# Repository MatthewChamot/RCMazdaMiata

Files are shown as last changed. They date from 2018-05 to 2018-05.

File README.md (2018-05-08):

# RCMazdaMiata
Project by Matthew Chamot

Arduino code and CAD for a remote-controlled scale model of a Mazda Miata.

After building a few plastic model cars, I wished they could actually move and I could race them around like an RC car.  This project does exactly that.  A 1:24 scale model of a Mazda Miata had its plastic engine swapped with an electric motor and it was off to the races.

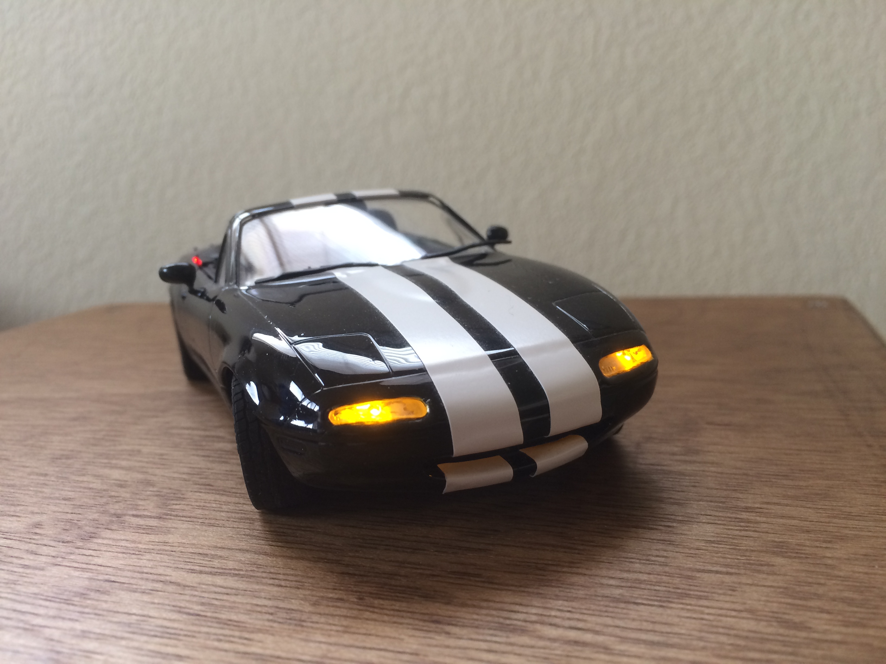
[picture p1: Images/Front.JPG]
miata image


#### Description
The RC Mazda Miata utilizes a small DC gearmotor for driving, sub-mirco servo for steering, and a Bluetooth module for communication.  The processing power comes from a Teensy LC which handles the signals from the controller. The controller in this case was a simple android phone that sends the commands via Bluetooth. The car also incorporates working headlights and taillights, an embedded charging circuit beneath the license plate, and everything still fits under the body of the original model. 

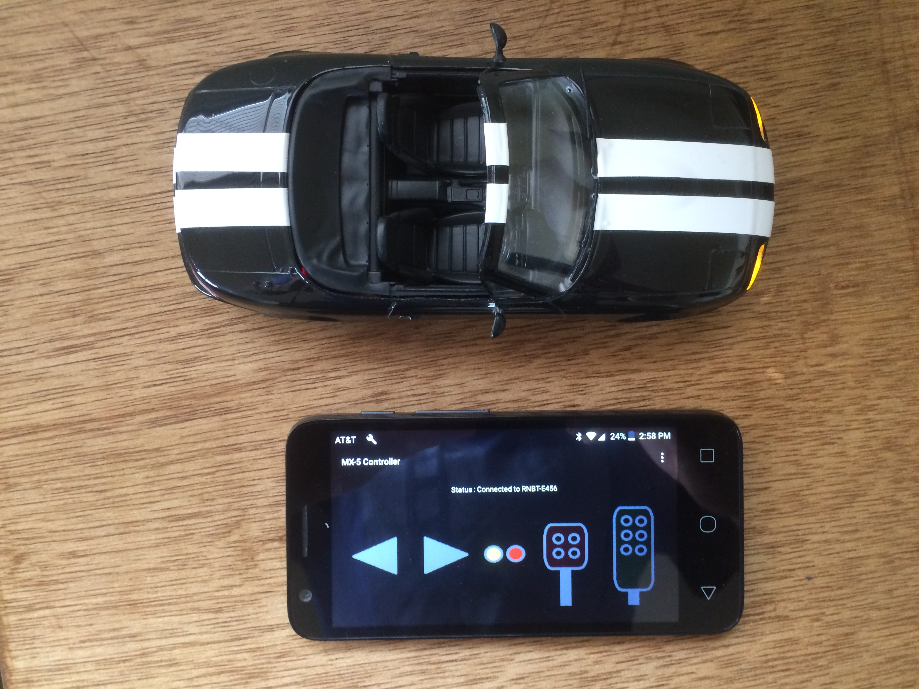
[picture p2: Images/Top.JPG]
miata image

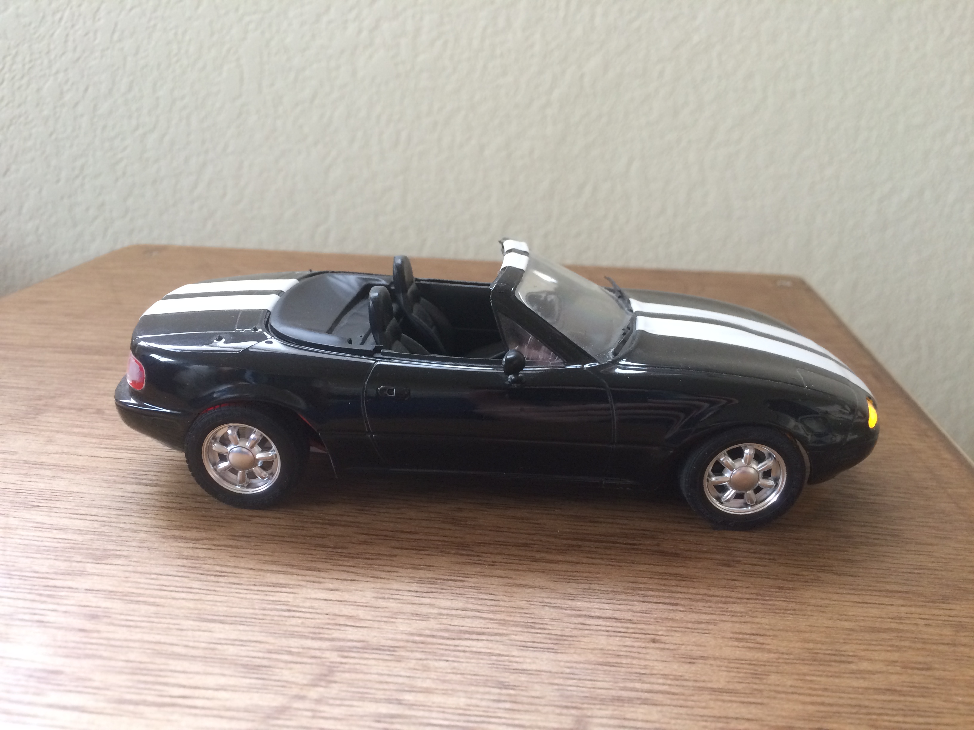
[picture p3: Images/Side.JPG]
miata image

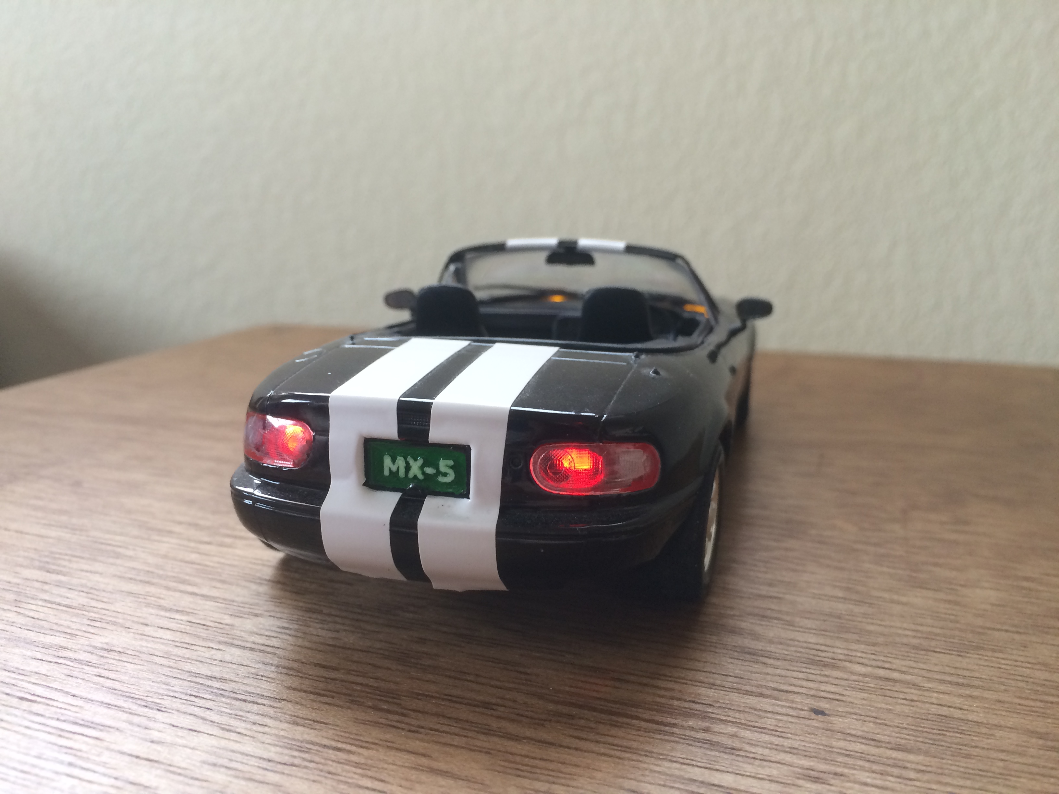
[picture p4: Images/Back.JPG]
miata image


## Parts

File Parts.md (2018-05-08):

## Parts Used

| Part | Quantity | Source |
| --- | :---: | --- |
| Tamiya Mazda Eunos Roadster	 | 1 | eBay				 |
| Micro Gearmotor  		 | 1 | https://www.sparkfun.com/products/12316  |
| Sub-Micro Servo | 1 | https://www.sparkfun.com/products/9065 |
| Teensy LC 		 | 1 | https://www.sparkfun.com/products/13305  |
| SparkFun Bluetooth Modem | 1 | https://www.sparkfun.com/products/12577  |
| SparkFun LiPo Charger Basic | 1 | https://www.sparkfun.com/products/10217  |
| Lithium Ion Battery 		 | 1 | https://www.sparkfun.com/products/13851  |
| Sparkfun Motor Driver 	 | 1 | https://www.sparkfun.com/products/9457 |
| LED - Basic Yellow 3mm  	 | 2 | https://www.sparkfun.com/products/532 |
| LED - Basic Red 3mm 	 | 2 | https://www.sparkfun.com/products/533 |
| SPDT Mini Power Switch 	 | 1  	 | https://www.sparkfun.com/products/102 |

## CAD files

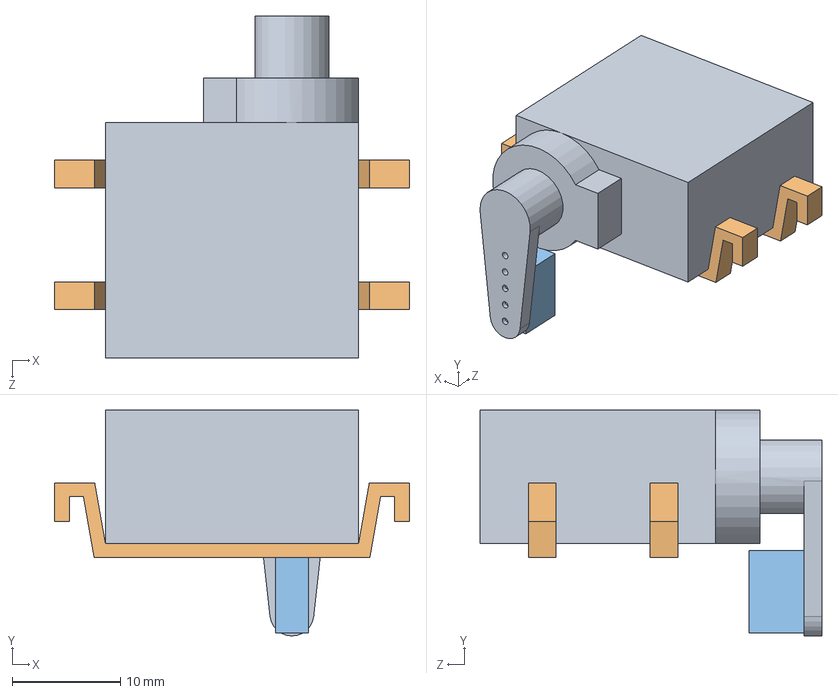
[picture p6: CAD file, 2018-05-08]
Miata_Parts/Servo Assembly.SLDASM
32.8 x 20.9 x 31.5 mm
Servo
Servo Strap x 2
Servo Block

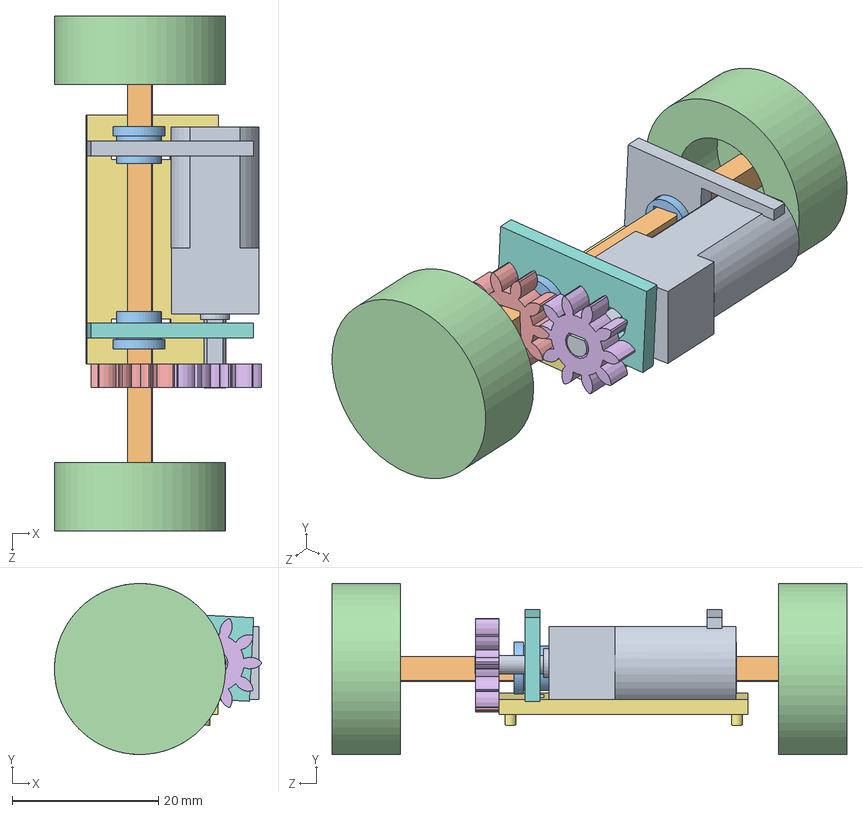
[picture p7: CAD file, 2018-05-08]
Miata_Parts/Motor Assembly.SLDASM
28.3 x 23.4 x 70.3 mm
Motor
Axle
Bushing x 2
Tire x 2
Gear2A
Gear2M
Motor Base
Motor Left
Motor Right

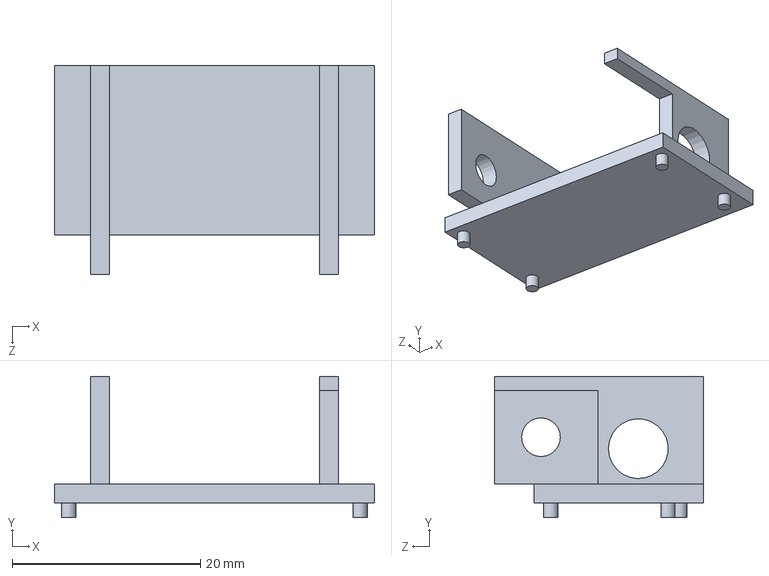
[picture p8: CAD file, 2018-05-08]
Miata_Parts/Motor Mount.SLDPRT
34.0 x 15.0 x 22.2 mm

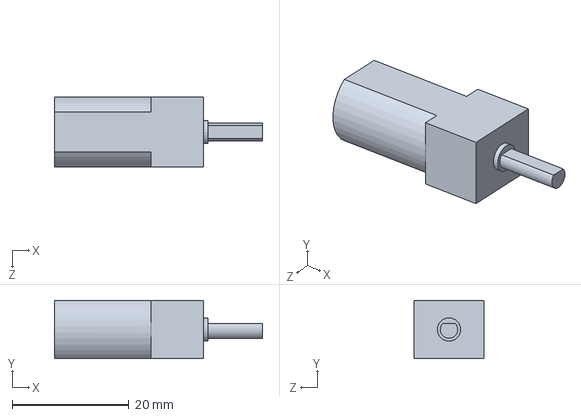
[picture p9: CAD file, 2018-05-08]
Miata_Parts/Motor.SLDPRT
35.6 x 9.96 x 12.0 mm

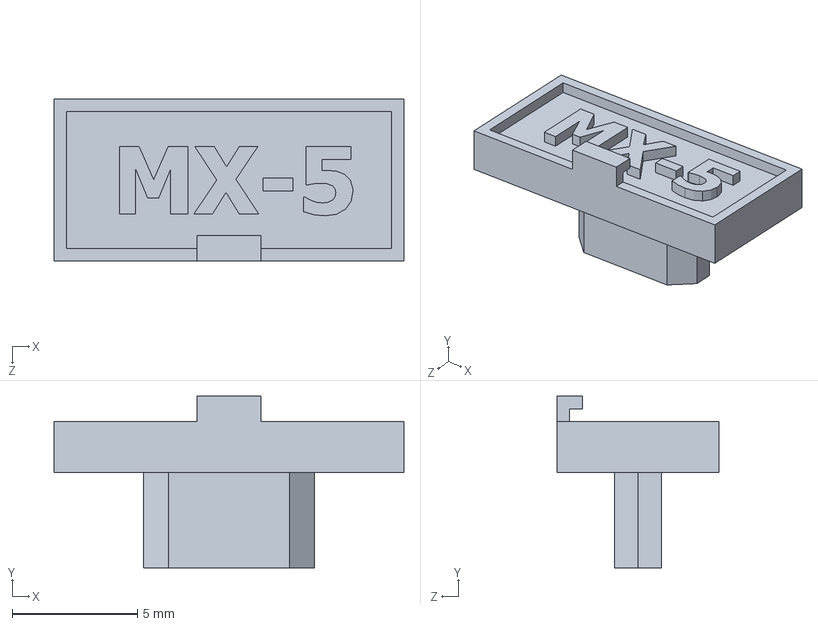
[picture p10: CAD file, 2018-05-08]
Miata_Parts/Plate.SLDPRT
14.0 x 6.86 x 6.48 mm

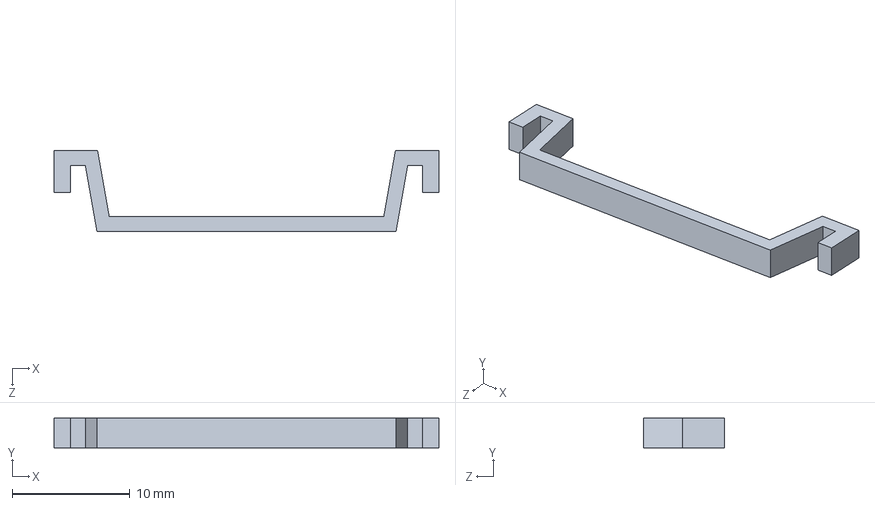
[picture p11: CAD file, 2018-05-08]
Miata_Parts/Servo Strap.SLDPRT
32.8 x 2.54 x 6.86 mm

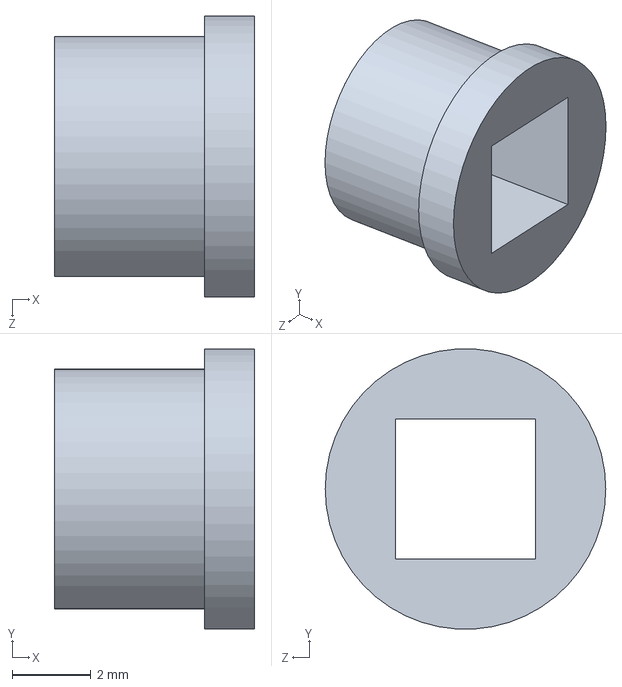
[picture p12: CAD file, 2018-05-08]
Miata_Parts/Bushing.SLDPRT
5.08 x 7.10 x 7.11 mm

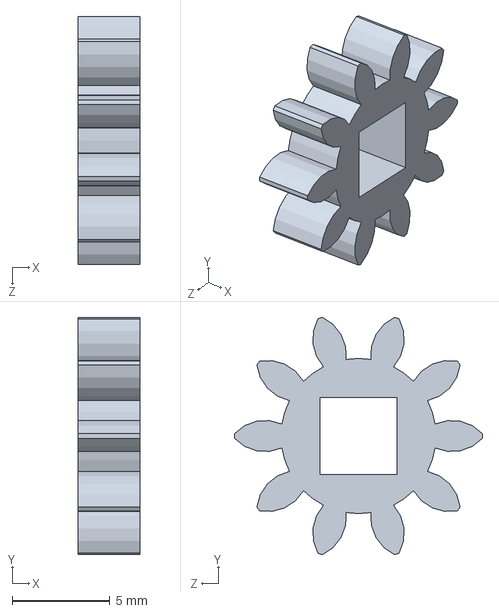
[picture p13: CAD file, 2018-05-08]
Miata_Parts/Gear2A.SLDPRT
3.17 x 12.2 x 12.7 mm

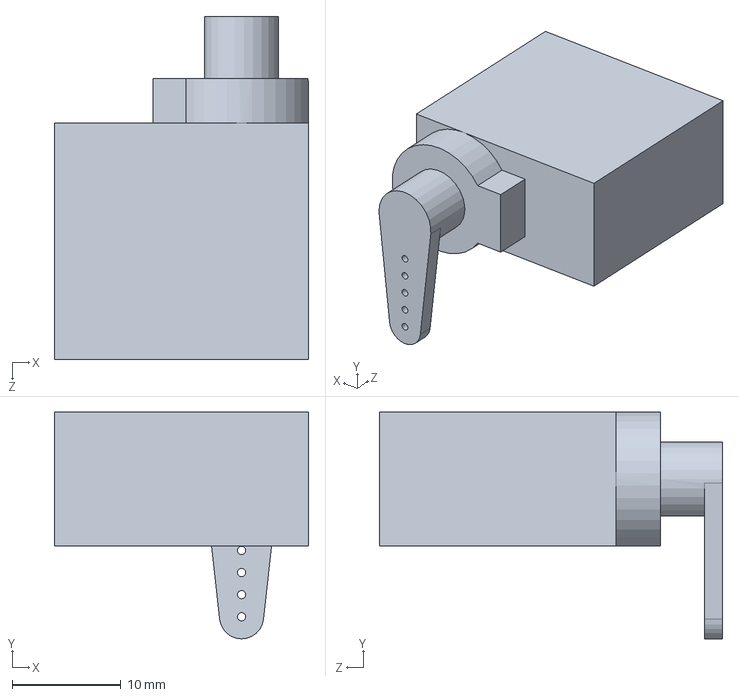
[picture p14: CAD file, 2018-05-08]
Miata_Parts/Servo.SLDPRT
23.4 x 20.9 x 31.5 mm

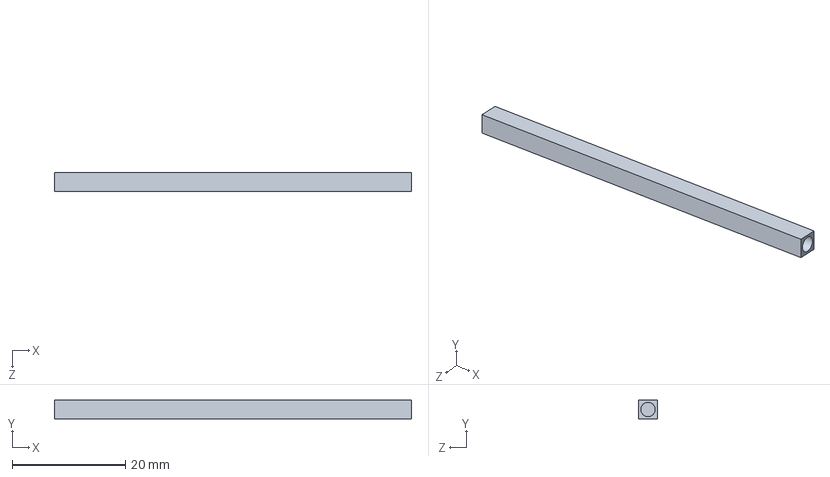
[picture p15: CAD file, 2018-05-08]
Miata_Parts/Axle.SLDPRT
63.1 x 3.30 x 3.30 mm

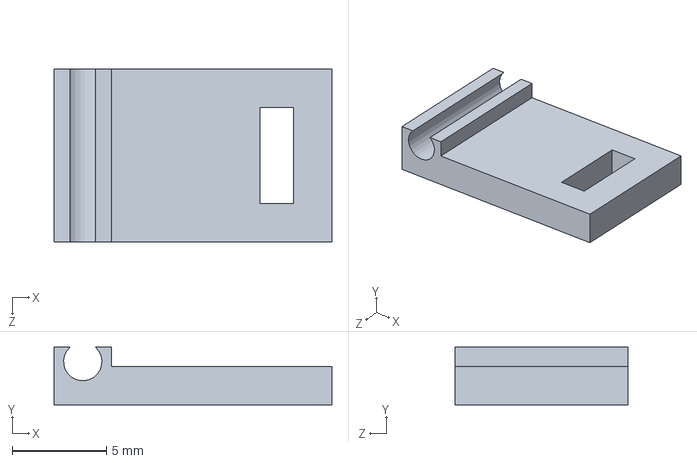
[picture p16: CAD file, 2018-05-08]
Miata_Parts/Rod Steering.SLDPRT
14.7 x 3.05 x 9.14 mm

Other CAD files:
Miata_Parts/Gear2M.SLDPRT
Miata_Parts/Axle.STL
Miata_Parts/Bushing.STL
Miata_Parts/Gear2A.STL
Miata_Parts/Gear2M.STL
Miata_Parts/Motor Mount.STL
Miata_Parts/Plate.STL
Miata_Parts/Rod Steering.STL
Miata_Parts/Servo Strap.STL

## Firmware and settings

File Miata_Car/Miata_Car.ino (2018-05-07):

//  Created by Matthew Chamot
//  For a Teensy LC
//  December 2017


#include <SparkFun_TB6612.h>
#include <Servo.h>

// Define pins for motor driver
#define AIN1 19
#define AIN2 20
#define PWMA 22
#define STBY 17

#define HLT 12  // Headlight
#define TLT 14  // Taillight


const int offsetA = 1;

Motor motor1 = Motor(AIN1, AIN2, PWMA, offsetA, STBY);

// Define servo for steering
Servo myservo;

char data = 0;

void setup() {
  Serial1.begin(115200);
  pinMode(HLT,OUTPUT);
  pinMode(TLT,OUTPUT);
  myservo.attach(6); 

}

void loop()
{
    // Read a character sent from the controller over bluetooth and determine what action to do.
    if (Serial1.available()) {
      data = Serial1.read();
      if(data == '1') {
        digitalWrite(13, HIGH);
        Serial1.write("LED is on\n");
      }
      else if(data == '0') {
        digitalWrite(13, LOW);
        Serial1.write("LED is off\n");
      }
      else if(data == '2') {
        Serial1.write("Motor CW\n");
        motor1.drive(255,1000);
        motor1.brake();
      }
      else if(data == '3') {
        Serial1.write("Motor CCW\n");
        motor1.drive(-255,1000);
        motor1.brake();
      }
      else if(data =='4') {
        digitalWrite(HLT,HIGH);
        Serial1.write("Headlights On\n");
      }
      else if(data =='5') {
        digitalWrite(HLT,LOW);
        Serial1.write("Headlights Off\n");
      }
      else if(data =='6') {
        digitalWrite(TLT,HIGH);
        Serial1.write("Taillights On\n");
      }
      else if(data =='7') {
        digitalWrite(TLT,LOW);
        Serial1.write("Taillights Off\n");
      }
      else if(data =='l') {
        myservo.write(78);
        Serial1.write("Servo Right\n");
      }
      else if(data =='c') {
        myservo.write(88);
        Serial1.write("Servo Straight\n");
      }
      else if(data =='d') {
        myservo.write(98);
        Serial1.write("Servo Left\n");
      }
      else if(data == 'r') {
        Serial1.write("Motor CW On\n");
        motor1.drive(255);
      }
      else if(data == 'b') {
        Serial1.write("Motor CW Off\n");
        motor1.brake();
      }
      else if(data == 'f') {
        Serial1.write("Motor CCW On\n");
        motor1.drive(-255);
      }
      
      
      
    }    
}

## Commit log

2018-05-07 Add Arduino code for car
2018-05-08 Add CAD files
    [Axle.SLDPRT, Axle.STL, Bushing.SLDPRT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]
